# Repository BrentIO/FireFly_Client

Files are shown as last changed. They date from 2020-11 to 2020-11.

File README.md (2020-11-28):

# FireFly Client
#### About Project FireFly
Project FireFly is a low-voltage lighting control system consisting of momentary LED push buttons.  There are two types of devices: the controller and the client.  The controller and client are configured using the FireFly Configurator.

The FireFly Controller emits 5VDC on a pull-up resistor and detects a button press when the pin senses `LOW`.  The Controller may make a number of actions based on the button press event, including outputting voltage on another pin to a relay and/or broadcasting the event over MQTT.

The FireFly Client listens for MQTT messages from the Controller and uses those messages to determine when to change the luminance level of the button that was pressed, providing the user with feedback that the button was pressed.  FireFly Client can also change brightness levels based on MQTT messages to become more dim or brighter, such as at night or during the day.  Also supported are blink modes and snoring mode.

This project was inspired by [Jonathan Oxer's SuperHouseTV](https://www.superhouse.tv/25-arduino-home-automation-light-switch-controller/).

## Hardware
FireFly Client uses an ESP8266 over WiFi and supports up to 6 buttons being controlled.  An additional pin is used for resetting the controller to defaults.

| FireFly Client Position | Arduino Pin |
| -- | --|
| A | GPIO5 | 
| B | GPIO4 | 
| C | GPIO14 | 
| D | GPIO12 | 
| E | GPIO13 | 
| F | GPIO15 | 
| Reset | GPIO10 <sup>1</sup> | 

<sup>1</sup> To reset to provisioning mode, short to ground.

The Gerber, BOM, and Pick & Place files area all located in the [PCB](/hardware/PCB) folder.

Custom faceplates to support a 16mm button in a standard US electrical box are in the [faceplates](hardware/faceplates) folder.  Note, you must print both the faceplate and the matching adapter plate.

## Reset to Defaults
Grounding pin reset pin will cause the EEPROM to be marked as not provisioned and enable the user to re-enter provisioning mode.

## Prerequisite Libraries
ArduinoJson 6.16 or later
PubSubClient 2.8.0 or later

## Installation from Source
External libraries required are ArduinoJson, which is used to parse JSON files, and PubSubClient, which is used to send and receive MQTT messages.

After installation, the ESP8266 will boot into a provisioning state, having created its own WiFi hotspot based on the MAC address of the device.  When you connect to the `FireFly-XXXXXXXXXX` SSID, you will be assigned a DHCP address by FireFly Client.  Point your web browser to `192.168.1.1` to begin provisioning.

You must also flash the SPIFFs, which contains assets for the provisioning server.  The easiest way to flash the SPIFFs is using ESP8266 filesystem uploader from https://github.com/esp8266/arduino-esp8266fs-plugin.

## Installation from Release Package
You can also install a pre-compiled version by downloading one of the [releases](https://github.com/BrentIO/FireFly_Client/releases).  To flash the ESP8266, install ESPTool from https://github.com/espressif/esptool, if it is not already installed on your system.

Flashing the bootloader and the SPIFFs can be done in a single command:
```python3 esptool.py --port {PORT} --baud 115200 write_flash 0x00000 {BOOTLOADER_FILE} 0x00200000 /{SPIFF_FILE}```

## Provisioning
Before the device can be used it must be provisioned.  If you have connected LEDs to the various ports, you will notice them "rotating" in quick succession through each LED.

The process of provisioning requires three pieces of data to be input: the SSID of the WiFi access point you wish to use, the WPA key for the access point, and a IP address or FQDN of the <a href="https://github.com/BrentIO/FireFly_Configurator">Configurator</a> server to retrieve the bootstrap file.  You do not need to use the same access point for production as you do to bootstrap the device.

If the device is unable to connect to the WiFi network specified, or if the bootstrap file is not able to be retrieved, the device will automatically return to provisioning mode after timing out.  Simply reconnecting to the WiFi and re-pointing your browser to `192.168.1.1` will display the error message that occurred.

## Bootstrapping
The bootstrap is simply a JSON document that outlines the settings for the FireFly Client to use, including the WiFi SSID and key, MQTT server information, and definitions of the buttons assigned to this client.  Upon a successful bootstrap retrieval it will be written to the ESP8266's EEPROM.

IP addresses are always assigned via DHCP.

There is a definite limit to the number of times the ESP8266 EEPROM can be written to, and **you should minimize the number of times the version number changes in your bootstrap file to avoid unnecessary writing to the EEPROM.**

You may specify up to 8 defined intensities within the bootstrap, keeping in mind that `ON` and `OFF` are reserved and you do not need to include them.

## Firmware Upgrades
OTA firmware updates are supported, but as of version 1.14, OTA SPIFFs are **not** supported.  Firmware can defined in the Configurator and, using MQTT, the firmware update will be requested.

## Health and Status
FireFly will send both solicited and unsolicited health status messages on the `client` topic.  See MQTT Topics for more information.

## MQTT Topics
### Client Management Requests
FireFly will accept requests for certain actions over the `client` topic specified in the bootstrap, for example `/client/A1B2C3D4E5F6/health/get` will request the device's status to be sent.  The resulting health data will be returned on several topics:
- `/client/A1B2C3D4E5F6/uptime`, the number of milliseconds since the last boot of the device up to the maximum value of `unsigned long`.
- `/client/A1B2C3D4E5F6/status`, typically `ONLINE`.
- `/client/A1B2C3D4E5F6/ip`, the IP address of the device.
- `/client/A1B2C3D4E5F6/firmware`, the current firmware revision.
- `/client/A1B2C3D4E5F6/deviceName`, the name of the device, in this case, `A1B2C3D4E5F6`.
- `/client/A1B2C3D4E5F6/name`, the friendly name of the device.

Firmware can be updated by sending a message to the topic `/client/A1B2C3D4E5F6/firmware/set` with a payload containing the URL of the BIN file to download.  This should be done using the Configurator.

The bootstrap can also be updated by sending a message to the topic `/client/A1B2C3D4E5F6/bootstrap/set` with the URL of the bootstrap file.  This should be done using the Configurator.

### LED Control Requests
FireFly Client will accept requests for certain actions over the `event` topic specified in the bootstrap.

FireFly Client supports a number of message types to provide you with maximum control of each LED by button name, color, or globally for all buttons.  For brightness, either the percentage brightness or an enumerated name defined in the bootstrap can be used.  Reserved illumination names are `ON`, which set the LED brightness to 100%, and `OFF`, which will set the LED brightness to 0%.

**Button Pressed Event for LIVING_ROOM_1 Switch 4 Button 3:**
Post to topic: `/button/S4B3`
```
{
    "type": "EVENT",
    "value": "CLOSED",
    "actor": "LIVING_ROOM_1"
}
```

**Button Released Event for LIVING_ROOM_1 Switch 4 Button 3:**
Post to topic: `/button/S4B3`
```
{
    "type": "EVENT",
    "value": "OPEN"
}
```

**Set brightness level to the defined intensity DAYTIME for all buttons on LIVING_ROOM_1 Switch:**
Post to topic: `/button/LIVING_ROOM_1`
```
{
    "type": "SWITCH_NAMED",
    "value": "DAYTIME"
}
```

**Set brightness level to 70% for LIVING_ROOM_1 Switch 4 Button 3:**
Post to topic: `/button/S4B3`
```
{
    "type": "BUTTON_NUMERIC",
    "value": 70
}
```

**Set brightness level to defined intensity DAYTIME for LIVING_ROOM_1 Switch 4 Button 3:**
Post to topic: `/button/S4B3`
```
{
    "type": "BUTTON_NAMED",
    "value": "DAYTIME"
}
```

**Set LIVING_ROOM_1 Switch 4 Button 3 to toggle Snore:**
Post to topic: `/button/S4B3`
```
{
    "type": "BUTTON_SNORE"
}
```

**Set LIVING_ROOM_1 Switch 4 Button 3 to toggle Blink:**
Post to topic: `/button/S4B3`
```
{
    "type": "BUTTON_BLINK"
}
```

**Set brightness level to 70% for all GREEN LEDs:**
Post to topic: `/button/global`
```
{
    "type": "COLOR_NUMERIC",
    "value": 70,
    "actor": "GREEN"
}
```

**Set brightness level to the defined intensity DAYTIME for all GREEN LEDs:**
Post to topic: `/button/global`
```
{
    "type": "COLOR_NAMED",
    "value": "DAYTIME",
    "actor": "GREEN"
}
```

**Set all BLUE LEDs to toggle Snore:**
Post to topic: `/button/global`
```
{
    "type": "COLOR_SNORE",
    "actor": "BLUE"
}
```

**Set BLUE LEDs to toggle Blink:**
Post to topic: `/button/global`
```
{
    "type": "COLOR_BLINK",
    "actor": "BLUE"
}
```

**Set all LEDs to toggle Snore:**
Post to topic: `/button/global`
```
{
    "type": "GLOBAL_SNORE"
}
```

**Set all LEDs to toggle Blink:**
Post to topic: `/button/global`
```
{
    "type": "GLOBAL_BLINK"
}
```

**Set all LEDs to 70% brightness level**
Post to topic: `/button/global`
```
{
    "type": "GLOBAL_NUMERIC",
    "value": 70
}
```
**Set brightness level to the defined intensity DAYTIME for all LEDs:**
Post to topic: `/button/global`
```
{
    "type": "GLOBAL_NAMED",
    "value": "DAYTIME"
}
```

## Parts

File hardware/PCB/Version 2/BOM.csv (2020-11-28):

ID | Name | Designator | Footprint | Quantity | Manufacturer Part | Manufacturer | Supplier | Supplier Part | LCSC Assembly
1 | 10K | R5,R4,R3,R2,R1 | R0402 | 5 | 0402WGF1002TCE | UniOhm | LCSC | C25744 | Yes
2 | Secondary | RJ45-SECONDARY | DS1128-06-S8B0P-X | 1 | DS1128-06-S8B0P-X | CONNFLY | LCSC | C86575
3 | Primary | RJ45-PRIMARY | DS1128-06-S8B0P-X | 1 | DS1128-06-S8B0P-X | CONNFLY | LCSC | C86575
4 | 330uF | C4 | CAP-SMD_L7.3-W4.3-R-RD | 1 | T520D337M006ATE015 | KEMET | LCSC | C116744 | Yes
5 | 33uH | L1 | IND-SMD_L12.5-W12.5 | 1 | SWRB1205S-330MT | Sunlord | LCSC | C169386 | Yes
6 | Switch 4 | SW4 | CONN-TH_B4B-XH-A (LF)(SN) | 1 | B4B-XH-A(LF)(SN) | JST Sales America | LCSC | C144395
7 | Switch 6 | SW6 | CONN-TH_B4B-XH-A (LF)(SN) | 1 | B4B-XH-A(LF)(SN) | JST Sales America | LCSC | C144395
8 | Switch 5 | SW5 | CONN-TH_B4B-XH-A (LF)(SN) | 1 | B4B-XH-A(LF)(SN) | JST Sales America | LCSC | C144395
9 | Switch 1 | SW1 | CONN-TH_B4B-XH-A (LF)(SN) | 1 | B4B-XH-A(LF)(SN) | JST Sales America | LCSC | C144395
10 | Switch 3 | SW3 | CONN-TH_B4B-XH-A (LF)(SN) | 1 | B4B-XH-A(LF)(SN) | JST Sales America | LCSC | C144395
11 | Switch 2 | SW2 | CONN-TH_B4B-XH-A (LF)(SN) | 1 | B4B-XH-A(LF)(SN) | JST Sales America | LCSC | C144395
12 | SK32WA | D1 | SOD-123F_L2.8-W1.8-LS3.7-RD | 1 | SK32WA | SK | LCSC | C183472 | Yes
13 | ESP-12F | U1 | WIFIM-SMD_ESP-12F-ESP8266MOD | 1 | ESP-12F(ESP8266MOD) | Ai-Thinker | LCSC | C82891
14 | XL1509-3.3E1 | U2 | SOP-8_L4.9-W3.9-P1.27-LS6.0-BL | 1 | XL1509-3.3E1 | XLSEMI | LCSC | C74193 | Yes
15 | 1uF | C2 | C0402 | 1 | CL05A105KA5NQNC | SAMSUNG | LCSC | C52923 | Yes
16 | 470uF | C1 | CAP-SMD_BD10.0-L10.3-W10.3-RD | 1 | VEJ471M1ETR-1010 | LELON | LCSC | C176672 | Yes

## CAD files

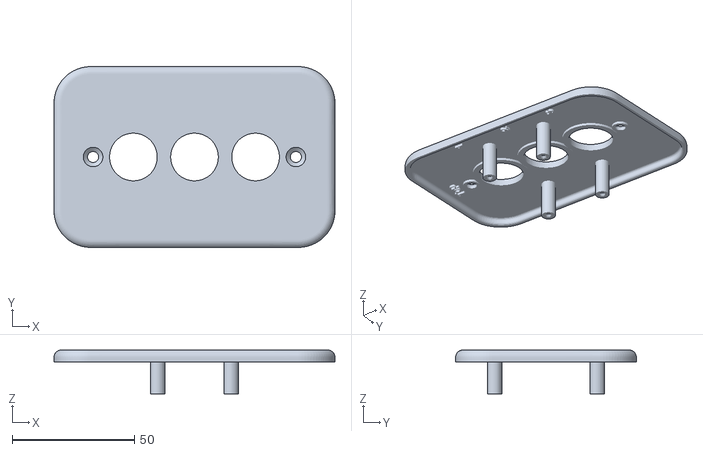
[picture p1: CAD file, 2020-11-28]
hardware/faceplates/3 Button.stl
115.0 x 74.0 x 18.0

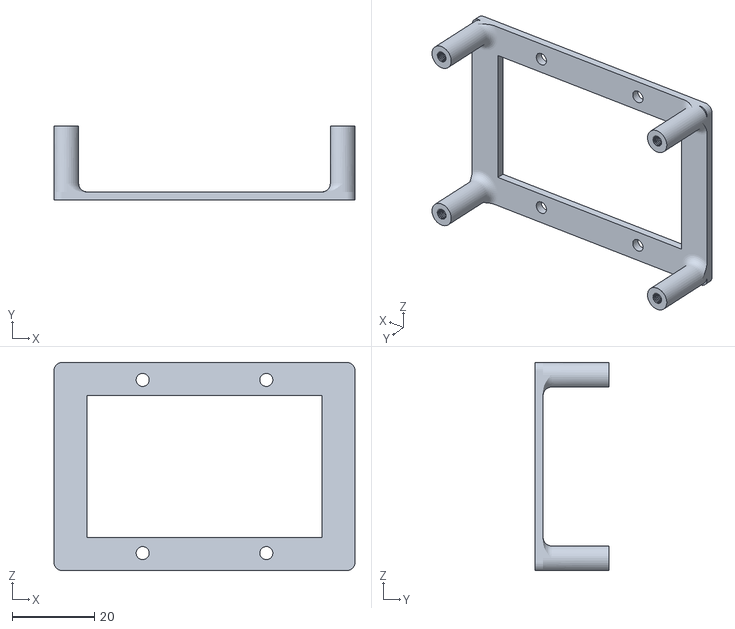
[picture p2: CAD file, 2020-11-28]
hardware/faceplates/Adapter Plate Standard.stl
73.0 x 18.0 x 50.5

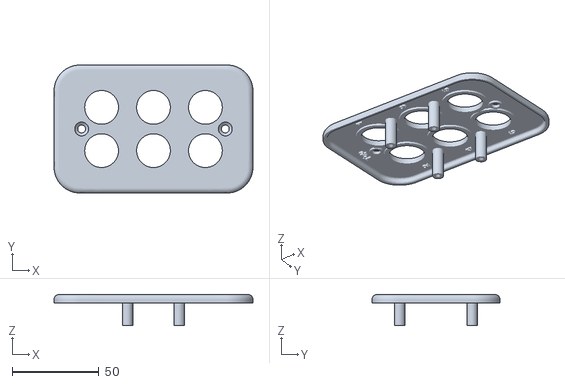
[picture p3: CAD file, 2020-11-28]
hardware/faceplates/6 Button.stl
115.0 x 74.0 x 18.0

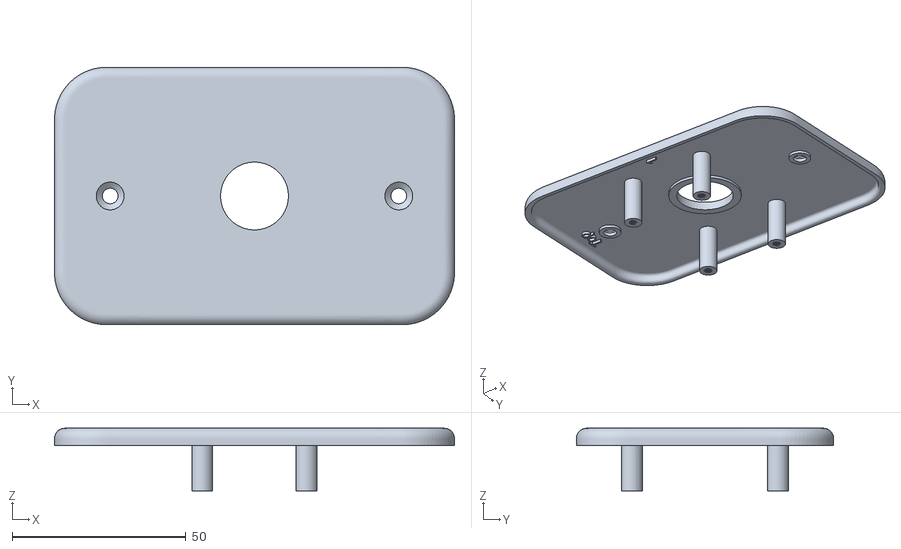
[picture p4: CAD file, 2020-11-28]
hardware/faceplates/1 Button.stl
115.0 x 74.0 x 18.0

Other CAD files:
hardware/faceplates/2 Button.stl
hardware/faceplates/4 Button.stl
hardware/faceplates/Adapter Plate 4 Button.stl

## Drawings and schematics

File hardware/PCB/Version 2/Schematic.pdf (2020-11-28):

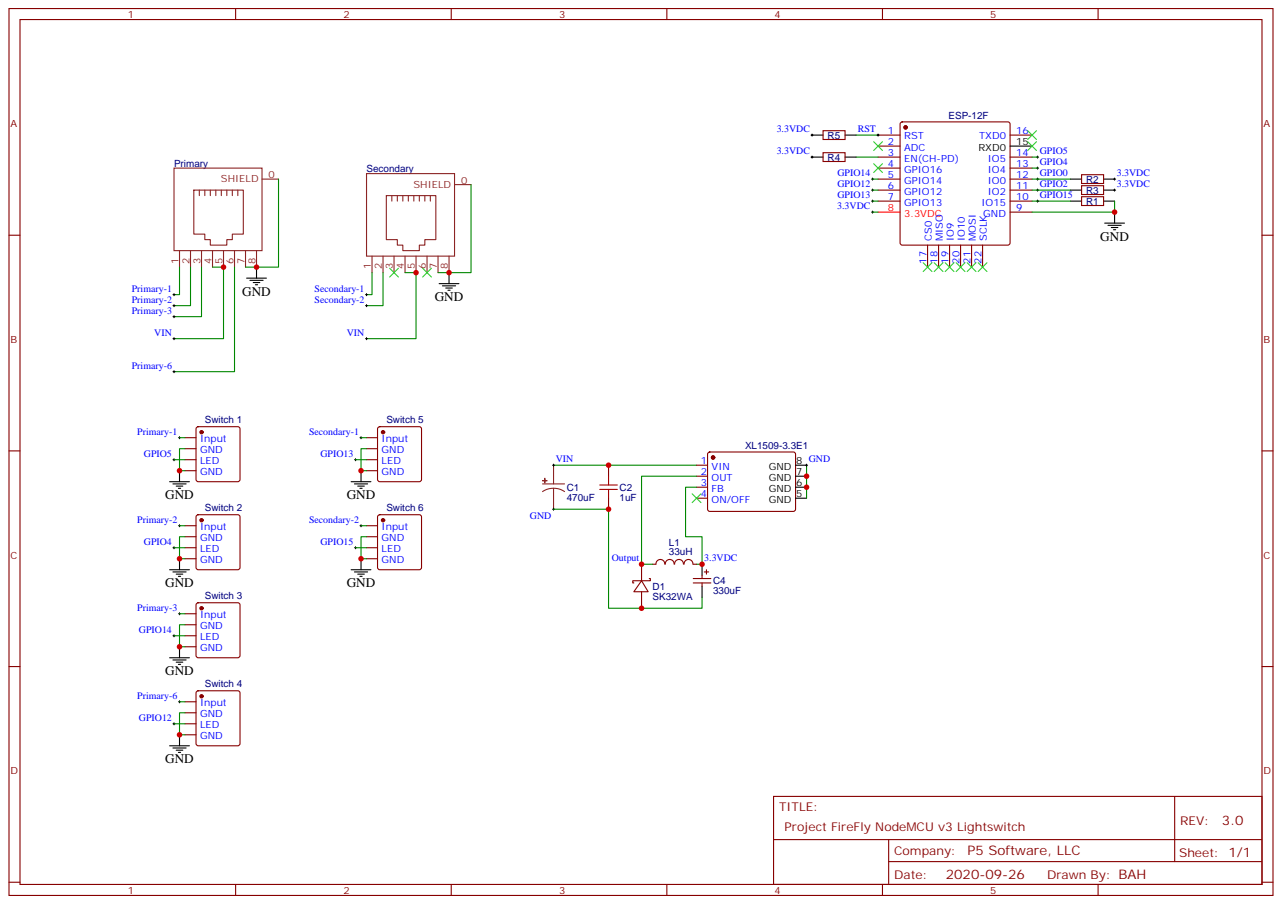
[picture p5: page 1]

TITLE:
Project FireFly NodeMCU v3 Lightswitch

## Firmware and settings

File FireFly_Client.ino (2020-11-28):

#include <ESP8266WiFi.h>
#include <PubSubClient.h>
#include <ArduinoJson.h>
#include <ESP8266WebServer.h>
#include <EEPROM.h>
#include <ESP8266HTTPClient.h>
#include <ESP8266httpUpdate.h>
#include <ESP8266mDNS.h>
#include <ESP8266HTTPUpdateServer.h>
#include <FS.h>   // Include the SPIFFS library, download from https://github.com/esp8266/arduino-esp8266fs-plugin
#include "Structures.h"

const char* FIRMWARE_VERSION = "1.14";
const char* PRODUCT_NAME = "FireFly Switch";

/* These are defined by the physical layout of the board by GPIO Number */
#define PORT_A 5
#define PORT_B 4
#define PORT_C 14
#define PORT_D 12
#define PORT_E 13
#define PORT_F 15
#define FACTORY_RESET 10

/* Define the LED style, where blink is binary 0/100%; snore is 0-100-0% */
#define STYLE_NORMAL 0
#define STYLE_BLINK 1
#define STYLE_SNORE 2
#define STYLE_ROTATE 3

#define EEPROM_SIZE 4096 //Number of bytes to use on the EEPROM
#define EEPROM_DATA_START 6 //Position where the actual EEPROM data begins; Prior to this is used to store provisioning data
#define HEALTH_UPDATE_EVERY_MS 1680000 //Every 28 minutes
#define LED_BLINK_MS 750
#define LED_COUNT_MAXIMUM 6 //Board maximum

unsigned long healthUpdateLastHandled = 0;
unsigned long blinkLastHandled = 0;

struct structSettings settings;

struct structLED leds[LED_COUNT_MAXIMUM]; //Board Maximum
int countOfLEDs = 0; //Essentially, the length of leds[].

WiFiClient espClient; //WiFi client on the ESP8266
PubSubClient mqttClient(espClient); //MQTT client binding to the ESP8266 WiFi
ESP8266WebServer webServer(80); //Web server client to handle provisioning
ESP8266HTTPUpdateServer httpUpdater; //HTTP server client to handle OTA updates

String errorMessage = "";

/******************************************* Setup and Loops *******************************************/


void setup() {

  EEPROM.begin(EEPROM_SIZE);

  //Set pin FACTORY_RESET to pullup
  pinMode(FACTORY_RESET, INPUT_PULLUP);

  //Determine if the FACTORY_RESET has been pulled low, if so, blow away the EEPROM
  if (digitalRead(FACTORY_RESET) == LOW) {

    //Destroy the EEPROM
    destroyEEPROM();

  }

  //Set the device name from the MAC address
  settings.deviceName = WiFi.macAddress();
  settings.deviceName.toUpperCase();
  settings.deviceName.replace(":", "");

  //Set the hostname
  WiFi.hostname("FireFly-" + settings.deviceName);

  //Check the provisioning status
  checkDeviceProvisioned();

  //Set the device's current mode depending on if it is provisioned or not
  if (settings.deviceIsProvisioned == false) {

    //Configure for provisioning mode
    setupProvisioningMode();

  } else {

    setupNormalMode();

  }
}


void loop() {

  if(settings.deviceIsProvisioned == false){
  
    loopProvisioningMode();
  
  }else{
  
    loopNormalMode();
  
  }
}


void setupNormalMode(){

  /*
    This version of setup will be run when the device has previously been provisioned.
  */

  //Read the data from EEPROM
  readNetworkFromEEPROM();
  readLEDsFromEEPROM();

  //Attempt to connect to the WiFi Network as a client
  WiFi.mode(WIFI_STA);

  if (WiFi.status() != WL_CONNECTED) {
    WiFi.begin(settings.network.ssidName.c_str(), settings.network.wpaKey.c_str());
  }

  //Print output while waiting for WiFi to connect
  while (WiFi.status() != WL_CONNECTED) {
    delay(200);
  }

  //Configure the mqtt Client
  mqttClient.setServer(settings.mqttServer.serverName.c_str(), settings.mqttServer.port);
  mqttClient.setCallback(mqttCallback);

  //Setup the LEDs for use
  setupLEDs();
  
}


void setupProvisioningMode() {
  /*
     Configures necessary items for when the device has not been provisioned.
  */

  //Set the number of LED's to 6
  countOfLEDs = 6;

  //Set each LED output pin to the port number
  leds[0].pin = PORT_A;
  leds[1].pin = PORT_B;
  leds[2].pin = PORT_C;
  leds[3].pin = PORT_D;
  leds[4].pin = PORT_E;
  leds[5].pin = PORT_F;

  //Set the LED to be an output and set the default brightness level while in provisioning mode
  for(int i=0; i < countOfLEDs; i++){

    pinMode(leds[i].pin, OUTPUT);
    setBrightness(&leds[i], int(PWMRANGE/16));

  }

  //By default, turn off the LED on port A, since the rotation will start there
  setBrightness(&leds[0], PWMRANGE);

  //Set the last handled to now so that the rotation will begin immediately
  blinkLastHandled = millis();

  //Set the default IP address, gateway, and subnet to use when in AP mode
  IPAddress ip(192, 168, 1, 1);
  IPAddress gateway(192, 168, 1, 1);
  IPAddress subnet(255, 255, 255, 0);

  WiFi.softAPConfig(ip, gateway, subnet);

  //Configure the device access point to be "FireFly-" + MAC address
  WiFi.softAP(("FireFly-" + settings.deviceName).c_str());

  //Start spiffs FS, where the html files are stored
  SPIFFS.begin();

  //Setup the web server to handle the POST request to the /bootstrap URL
  webServer.on(F("/bootstrap"), HTTP_POST, wwwHandleSubmit);

 //Setup the webserver to handle all requests
  webServer.onNotFound([]() {

    //Determine the method handler
    switch(webServer.method()){
      
      case HTTP_GET:
      
        //We only allow GET requests
        handleWebGet(webServer.uri());
        
        break;

      default:

        //We don't know how to handle this method, return 400
        webServer.send(400);
        
        break;
    }

  });

  //Set the MDNS name on the broadcast  
  MDNS.begin(settings.deviceName.c_str());

  //Allow uploads of firmware through the web server
  httpUpdater.setup(&webServer);

  MDNS.addService("http", "tcp", 80);

  //Start up the web server
  webServer.begin();

}


void loopNormalMode(){
  /*
    This version of the loop will be called when the device has previously been provisioned.
  */

  //The device has been provisioned, run the normal processes
  if (!mqttClient.connected()) {
    reconnectMQTT();
  }

  mqttClient.loop();

  //Blink the LEDs that need to be blinkLEDs if it's time to do so
  if ((millis() - blinkLastHandled) > LED_BLINK_MS) {
    blinkLEDs();
  }

  //Only snore every 40th clock cycle
  if (millis() % 60 == 0) {
    //Snore the LEDs that need to be snored
    snoreLEDs();
  }

  //See if it is time to send an unsolicited status message
  if ((millis() - healthUpdateLastHandled) > HEALTH_UPDATE_EVERY_MS) {
    handleHealth();
  }
}
  

void loopProvisioningMode(){

  /*
    This version of the loop handles web server requests and causes the LED's to rotate in sequential order, indcating the device needs provisioning.
  */

  //Setup a client handler
  webServer.handleClient();

  rotateLEDs();
  
}


/******************************************* LED Modes *******************************************/

void setupLEDs(void) {

  /* 
    Sets the pins and default brightness
  */

  for (int i = 0; i < countOfLEDs; i++) {

    //Set the pin for output
    pinMode(leds[i].pin, OUTPUT);

    setBrightness(&leds[i], F("DEFAULT"));

  }
}


void blinkLEDs() {

  /*
    Global function that blinks any LED's that have been set to blink.
  */

  //Find any LED's that should be blinking
  for (int i = 0; i < countOfLEDs; i++) {

    if (leds[i].style == STYLE_BLINK) {

      if (leds[i].brightness == 0) {

        //Turn on the LED to the pre-last value
        setBrightness(&leds[i], leds[i].styleData);

      } else {

        //Turn off the LED
        setBrightness(&leds[i], F("OFF"));

      }
    }
  }

  //Set the blink handler
  blinkLastHandled = millis();
}


void snoreLEDs() {

  /*
    Global function that snores any LED's that have been set to snore.
  */

  //Find any LED's that should be snoring
  for (int i = 0; i < countOfLEDs; i++) {

    if (leds[i].style == STYLE_SNORE) {

      //Determine if we are increasing (not zero) or decreasing (zero)
      if (leds[i].styleData != 0) {

        //Increment the brightness
        leds[i].brightness++;

        //If we are now greater than PWMRANGE, switch the direction for the next iteration
        if (leds[i].brightness > PWMRANGE) {
          leds[i].styleData = 0;
        }

        //Set the new value
        setBrightness(&leds[i], leds[i].brightness);

      } else {

        //Decrement the brightness
        leds[i].brightness--;

        //If we are now less than 10, switch the direction for the next iteration; A value of less than 10 makes the LED flash off, so count it as 0.
        if (leds[i].brightness < 10) {
          leds[i].styleData = 1;
        }

        //Set the new brightness value
        setBrightness(&leds[i], leds[i].brightness);

      }
    }
  }
}


void rotateLEDs(){

  /*
    A global function that rotates between each LED in the count and causes it to flash in sequential order, on or off.
  */

  //Only run this function every 1 second
  if(millis() - blinkLastHandled < 200){
    return;
  }

  //Find any LED's that should be on
  for (int i = 0; i < countOfLEDs; i++) {

    if(leds[i].brightness == PWMRANGE){

      //Turn off this LED
      setBrightness(&leds[i], int(PWMRANGE/16));

      if((i+1) == countOfLEDs){

        //This is LED 5, turn on LED 0
        setBrightness(&leds[0], PWMRANGE);

      }else{
        //Turn on the next LED
        setBrightness(&leds[(i+1)], PWMRANGE);

      }

      //Update the last handled
      blinkLastHandled = millis();
      return;
    }

  }
   
}


void setBrightness(structLED *ptrLed, int brightness) {

  /*
    Sets the LED's brightness to a given brightness number, as a PWM value
  */

  ptrLed->brightness = brightness;

  analogWrite(ptrLed->pin, ptrLed->brightness);
}


void setBrightness(structLED *ptrLed, String intensity) {

  /*
    Sets the LED's brightness to a given named intensity
  */

  //Clean up the string
  intensity.toUpperCase();
  intensity.trim();

  //Find the intensity requested, if it exists
  for (int i = 0; i < ptrLed->countOfIntensities; i++) {

    if (ptrLed->intensities[i].name == intensity) {

      ptrLed->brightness = calculateBrightness(ptrLed->intensities[i].brightness);

    }
  }

  //Also consider binary ON (100) and OFF (0)
  if (intensity == F("OFF")) {
    ptrLed->brightness = calculateBrightness(0);
  }

  if (intensity == F("ON")) {
    ptrLed->brightness = calculateBrightness(100);
  }

  //Set the brightness, which will also do nothing if the intensity isn't defined
  analogWrite(ptrLed->pin, ptrLed->brightness);

}


void turnOffAllLEDs() {

  /*
    Turns off all LED's
  */

  //Turn off the LEDs
  for (int i = 0; i < countOfLEDs; i++) {

    //Remember the current brightness setting, except blinking which could be temporarily off
    if (leds[i].style != STYLE_BLINK) {

      leds[i].styleData = leds[i].brightness;

    }
    //Turn off the LED
    setBrightness(&leds[i], F("OFF"));
  }

}


void restoreAllLEDs() {

  /*
    Restores all LED's to their previous brightness level.
  */

  //Turn off the LEDs
  for (int i = 0; i < countOfLEDs; i++) {

    //Set the brightness to the previous value
    setBrightness(&leds[i], leds[i].styleData);
  }

}


/******************************************* MQTT *******************************************/

void mqttCallback(char* topic, byte* payload, unsigned int length) {
  /*
    Handles all incoming requests for subscribed topics
  */

  String receivedPayload = "";

  //Assemble the payload data
  for (int i = 0; i < length; i++) {
    receivedPayload = String(receivedPayload + (char)payload[i]);
  }

  //Clean the payload received
  receivedPayload.trim();

  //Pass the payload off for further processing
  handleMQTTMessageReceived(String(topic), receivedPayload);

  

}


void handleMQTTMessageReceived(String topic, String payload) {
  /*
    Handles incoming messages from MQTT.  Payloads must exactly match.
  */

  //See if the payload requests a restart
  if (topic == settings.mqttServer.clientTopic + "/restart" && payload != "") {

    turnOffAllLEDs();

    publishMQTT(settings.mqttServer.clientTopic + "/status", F("RESTARTING"));

    delay(500);

    ESP.restart();

    return;

  }

  //See if the payload requests a health check
  if (topic == settings.mqttServer.clientTopic + "/health/get") {

    handleHealth();

    return;
  }

  //See if the payload requests a firmware update check
  if (topic == settings.mqttServer.clientTopic + "/firmware/set") {

    checkFirmwareUpgrade(payload);

    return;
  }

  //See if the payload requests a bootstrap update check
  if (topic == settings.mqttServer.clientTopic + "/bootstrap/set") {

    //Success, restart to pick up changes
    turnOffAllLEDs();

    publishMQTT(settings.mqttServer.clientTopic + "/status", F("BOOTSTRAPPING"));

    if(retrieveBootstrap(payload) == false){

      //Publish that the bootstrap failed
      publishMQTT(settings.mqttServer.clientTopic + "/status", F("BOOTSTRAP_FAILED"));
      publishMQTT(settings.mqttServer.clientTopic + "/errorMessage", errorMessage);

      //Turn on the LED's again
      restoreAllLEDs();

    }else{

      publishMQTT(settings.mqttServer.clientTopic + "/status", F("RESTARTING"));

      delay(500);

      ESP.restart();

    }

    return;
  }

  //See if the topic was an event
  if (topic.startsWith(settings.mqttServer.eventTopic) == true) {

    if (topic.endsWith("/global") == true) {
      handleGlobalEventTopic(topic, payload);
    }
    else {
      handleEventTopic(topic, payload);
    }
  }

}


void publishMQTT(String topic, String payload) {
  /*
     Sends the requested payload to the requested topic.
  */

  //Clean the strings
  topic.trim();
  payload.trim();

  mqttClient.publish(String(topic).c_str(), String(payload).c_str());

}


void handleEventTopic(String topic, String payload) {

  String messageActor;

  //Get the button name from the topic
  messageActor = topic.substring(topic.lastIndexOf("/") + 1);

  //Fix the payload to be toUpperCase
  payload.toUpperCase();

  //Find the button
  for (int i = 0; i < countOfLEDs; i++) {

    if (leds[i].name == messageActor) {

      //See if this is a button push
      if (payload == F("ON")) {

        //Remember the current brightness value
        leds[i].styleData = leds[i].brightness;

        //Set the brightness to OFF while the button is being pushed
        setBrightness(&leds[i], F("OFF"));
      }

      //See if this is a button release
      if (payload == F("OFF")) {

        //Button has been released, turn the LED back on to its previous level if we know it, otherwise use the default
        if (leds[i].styleData != 0) {

          //Restore the previous value
          setBrightness(&leds[i], leds[i].styleData);

        } else {

          //Use the default
          setBrightness(&leds[i], F("DEFAULT"));

        }
      }

      //See if the controller is telling us the button has been pressed too many times
      if (payload == F("MINIMUM") || payload == F("MAXIMUM")) {

        //Flash the LED off then to maximum brightness three times quickly
        for(int flashCount = 0; flashCount < 3; flashCount++){

          //Turn the LED to maximum brightness briefly
          setBrightness(&leds[i], F("ON"));

          delay(100);

          setBrightness(&leds[i], F("OFF"));

          delay(100);

        }

        //Reset the brightness value
        setBrightness(&leds[i], leds[i].styleData);
        
      }
    }
  }
}
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

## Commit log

2019-08-26 Fixed the length to a shorter value for EEPROM
    [FireFly_Client.ino]
2020-10-18 Added handling for missing deviceName and firmware
2020-11-08 Added error message on retry
    [FireFly_Client.ino]
2020-11-08 Fixed nomenclature for consistency
    [FireFly_Client.ino]
2020-11-08 Fixed defect; Added turning off LED's during bootstrap
    [FireFly_Client.ino]
2020-11-09 Updated maximums and minimums button
2020-11-09 Fixed case
2020-11-28 Updated readme, hardware data, and hardware information.
    [1 Button.stl, 2 Button.stl, 3 Button.stl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]
